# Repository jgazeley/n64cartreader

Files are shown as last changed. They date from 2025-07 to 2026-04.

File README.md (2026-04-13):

# N64 Pico Cart Reader V2

A simple, open-source N64 cartridge reader powered by a Raspberry Pi Pico. Plug it in via USB to dump ROMs and back up saves directly to your computer using a web browser or command line.

Device in Action

## Features

- **Full ROM dumping** for retail N64 cartridges (up to 32 MB)
- **Save read/write/restore** for all retail save types:
  - SRAM (e.g. 1080 Snowboarding, Ocarina of Time)
  - EEPROM 4K/16K (e.g. GoldenEye, Super Mario 64)
  - FlashRAM (e.g. Majora's Mask, Pokemon Stadium)
  *(For a full list of N64 games and their save types, see [Micro-64's Game Save List](http://micro-64.com/database/gamesave.shtml))*
- **Controller Pak (MPK)** export/import
- **GameShark** cartridge export/import/restore
- **Web Serial GUI** — runs in Chrome/Edge, no install required
- **Python CLI** for all other users
- **3.3V-native design** — no level shifting needed, lower BOM cost
- **Automatic cart identification** — detects game, ROM size, and save type from a built-in catalog

## Getting Started

See [docs/GETTING_STARTED.md](docs/GETTING_STARTED.md) for full setup instructions.

### Quick Start

1. Flash the `pico_headless_demo.uf2` firmware to your Pico (hold BOOTSEL while plugging in USB, then drag the file onto the drive).
2. Insert an N64 cartridge.
3. Open the [Web Serial UI](host-tools/web/index.html) in Chrome or Edge, or use a CLI:

**Windows (PowerShell):**
```powershell
./host-tools/powershell/N64CartReader.ps1 -Port COM5
```

**Windows/macOS/Linux (Python):**
```bash
# example for windows
python3 host-tools/python/pico_pak_n64_magic_cli.py --port /dev/ttyCOM5 n64-cart-id --rescan
# example for linux
python3 host-tools/python/pico_pak_n64_magic_cli.py --port /dev/ttyACM0 n64-cart-id --rescan
```

## Project Layout

```
firmware/
  rp2040/          C-based firmware for the Raspberry Pi Pico (timing-critical bus logic)
host-tools/
  powershell/      Native CLI for Windows (no setup needed); also supports macOS/Linux
  python/          Cross-platform CLI for validation, diagnostics, and batch scripts
  web/             Easiest, driverless browser-based interface using Web Serial
hardware/
  board/           V2 hardware project (KiCad PCB, schematics, and BOM)
enclosure/
  board/           3D-printable protective case (FreeCAD and STL files)
docs/              Technical guides, hardware documentation, and troubleshooting
LICENSES/          Third-party license texts for shared components
```

## Web Serial UI

The browser-based interface is the easiest way to use the reader. It works in Chrome and Edge via the Web Serial API. No drivers or software installation required.

Open `host-tools/web/index.html` directly in your browser, click Connect, and the UI will detect your cartridge and present options for ROM dumping, save export/import, and GameShark operations.

See [docs/WEB_SERIAL_UI.md](docs/WEB_SERIAL_UI.md) for details.

## Python CLI

The Python CLI provides full access to all device capabilities and is used for bench testing, validation, and scripted workflows.

```bash
cd host-tools/python

# Identify the cartridge
python3 pico_pak_n64_magic_cli.py --port /dev/ttyACM0 n64-cart-id --rescan

# Export a save
python3 pico_pak_n64_magic_cli.py --port /dev/ttyACM0 n64-export --out my_save.bin --sha256

# Import a save with verification
python3 pico_pak_n64_magic_cli.py --port /dev/ttyACM0 n64-import --in my_save.bin --verify

# Dump the full ROM
python3 pico_pak_n64_magic_cli.py --port /dev/ttyACM0 n64-rom-dump --out my_rom.z64

# Run the validation matrix
python3 n64_validation_matrix.py --port /dev/ttyACM0
```

## PowerShell CLI

A native alternative for Windows users (no installation required). Works with the built-in PowerShell 5.1 or PowerShell 7+ (`pwsh`) on any platform. See [Getting Started](docs/GETTING_STARTED.md) for Windows execution policy setup.

```powershell
# Interactive menu (use COMx on Windows, /dev/ttyACM0 on Linux)
./host-tools/powershell/N64CartReader.ps1 -Port COM5

# Export a save
./host-tools/powershell/Export-Save.ps1 -Port COM5 -Out my_save.bin

# Import a save with verification
./host-tools/powershell/Import-Save.ps1 -Port COM5 -In my_save.bin -Verify

# Dump the full ROM
./host-tools/powershell/Dump-Rom.ps1 -Port COM5 -Out my_rom.z64
```

## Building the Firmware

Requires the [Pico SDK](https://github.com/raspberrypi/pico-sdk) and CMake.

```bash
cd firmware/rp2040
export PICO_SDK_PATH=/path/to/pico-sdk
cmake -S . -B build
cmake --build build -j4 --target pico_headless_demo
```

Flash with picotool or drag `build/pico_headless_demo.uf2` onto the Pico in BOOTSEL mode.

## Hardware

The V2 board is a single PCB with an integrated N64 cartridge slot and Raspberry Pi Pico footprint. The design is in KiCad under `hardware/board/kicad/`.

Power is supplied through USB. The RP2040 runs at 3.3V, which matches N64 cartridge logic levels directly.

Pin mapping and board documentation are in [docs/HARDWARE.md](docs/HARDWARE.md).

## Troubleshooting

**Cartridge not detected or garbled header:**
Remove the cartridge, clean the edge connector contacts with isopropyl alcohol and a cotton swab, and reseat firmly.

**EEPROM save shows `type=none` after cart swap:**
Run `n64-cart-id --rescan` or retry 3-5 times. The Joybus bus needs a moment to settle after a physical swap.

**Controller probe returns `IO_ERR`:**
EEPROM cartridges and controllers share the same Joybus data line. Unplug one to test the other.

**Web Serial won't connect:**
Web Serial requires Chrome or Edge. Firefox and Safari are not supported. Make sure no other application (terminal, serial monitor) has the port open.

## V1 Legacy

The original N64 Cart Reader was built on an Arduino Mega 2560 with an SD card for storage and a serial terminal interface. That design is preserved in the `legacy/v1-arduino` branch.

See [docs/V1_LEGACY.md](docs/V1_LEGACY.md) for details on the original hardware.

## Acknowledgements

N64 Pico Cart Reader V2 was designed and implemented by Jayson Gazeley as an RP2040-based successor to the original Arduino N64 Cart Reader.

The project builds on prior open-source preservation work, especially:

- **[Sanni Cart Reader](https://github.com/sanni/cartreader)** (GPL-3.0) — foundational N64 cartridge interfacing logic
- **[drmdmp64_mass / DreamDumper64](https://github.com/nopjne/drmdmp64_mass)** by nopjne (BSD-2-Clause) — Joybus PIO and EEPROM reference implementation
- **skaman** — multi-console cart-reader modules
- **hkz & themanbehindthecurtain** — FlashRAM command documentation
- **Andrew Brown & Peter Den Hartog** — N64 controller protocol
- **libdragon** — N64 controller checksums

See [docs/CREDITS_AND_PRIOR_ART.md](docs/CREDITS_AND_PRIOR_ART.md) for full attribution and [docs/LICENSING.md](docs/LICENSING.md) for license details.

## References

- [Joybus Protocol](https://n64brew.dev/wiki/Joybus_Protocol)
- [N64 Hardware Architecture](https://www.copetti.org/writings/consoles/nintendo-64/)

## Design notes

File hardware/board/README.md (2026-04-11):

# N64 Pico Cart Reader V2 Hardware

This directory contains the custom KiCad PCB design files and fabrication outputs for the N64 Pico Cart Reader V2.

## Directory Structure

- **`docs/`**: Hardware documentation, including the current `PINMAP.md` that outlines the routing between the Raspberry Pi Pico and the N64 cartridge slot.
- **`kicad/`**: The complete, editable KiCad project (`.kicad_pro`, `.kicad_sch`, `.kicad_pcb`).
  - **`lib/`**: Custom project symbols and footprints (e.g., the N64 cartridge slot footprint).
- **`fabrication/`**: Board manufacturing outputs.
  - **`jlcpcb/`**: A known-good `.zip` file containing the Gerbers and drill files formatted and ready for upload to JLCPCB.
  - **`gerbers/`**: The individual, extracted Gerber and drill files.

## Hardware Quirk: EEPROM Latency
When testing the hardware, note that after a physical cartridge swap, the initial Joybus detection may return `type=none` for EEPROM saves. This is a known hardware limitation. It typically requires 3-5 retries or an explicit software rescan to allow the bus to settle.

## Licensing
The hardware design files (schematics, PCB layouts, custom footprints) are released under the [Creative Commons Attribution 4.0 International (CC BY 4.0)](https://creativecommons.org/licenses/by/4.0/) license. This license was chosen to maintain continuity with the hardware licensing of the original V1 Arduino-based project from which this work conceptually descends.

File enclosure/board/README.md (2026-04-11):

# N64 Pico Cart Reader V2 Enclosure

This directory contains the 3D printable enclosure files for the N64 Pico Cart Reader V2.

## Files

- **`freecad/`**: Original FreeCAD (`.FCStd`) source files. These are provided so you can remix, modify, or adjust the case design to fit your specific printing needs.
- **`stl/`**: Ready-to-print STL meshes. Import these directly into your slicer of choice (e.g., Cura, PrusaSlicer, OrcaSlicer) to generate the toolpaths for your 3D printer.

## Printing Recommendations

- **Material:** PLA, PETG, or ABS are all suitable.
- **Layer Height:** 0.2mm is recommended for a good balance of quality and print speed.
- **Infill:** 15-20% is typically sufficient for an enclosure.
- **Supports:** Check your slicer preview; some overhanging sections for the ports or mounting posts may require minimal supports depending on your printer's bridging capabilities.

## Licensing
The enclosure designs are provided under the [Creative Commons Attribution 4.0 International (CC BY 4.0)](https://creativecommons.org/licenses/by/4.0/) license.

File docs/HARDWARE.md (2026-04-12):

# Hardware Overview

## V2 Single-Board Reader (RP2040)

The V2 board is a single PCB integrating an N64 cartridge slot and a Raspberry Pi Pico (RP2040). It replaces the original Arduino Mega 2560 + shield design with a simpler, lower-cost solution.

### Design Highlights

- **3.3V-native:** The RP2040 and N64 cartridges both operate at 3.3V. No level shifters required.
- **No SD card:** All data transfer happens over USB. Saves and ROMs are streamed directly to the host.
- **Low BOM:** The minimum build requires the PCB, a Pico, the N64 cartridge slot connector, and passive components.
- **USB-powered:** No external power supply needed.

### Pin Mapping

The RP2040 GPIO assignments are defined in `firmware/rp2040/include/n64/pins.h`.

| Function | GPIO | N64 Slot Pin | Notes |
|---|---|---|---|
| AD0-AD15 | GPIO 0-15 | AD0-AD15 | 16-bit multiplexed address/data bus |
| SYSTEM_RESET | GPIO 16 | RESET | Active-high for bus reset |
| /WRITE | GPIO 17 | /WR | Active-low write strobe |
| /READ | GPIO 18 | /RD | Active-low read strobe |
| ALE_H | GPIO 19 | ALE_H | Address latch enable (high byte) |
| ALE_L | GPIO 20 | ALE_L | Address latch enable (low byte) |
| EEPROM DATA | GPIO 21 | EE_DAT | Shared Joybus data line for cartridge EEPROM/RTC and controller |
| EEPROM CLK | GPIO 22 | EE_CLK | Clock for cartridge EEPROM transfers |

### Power

- **VCC (3.3V):** Supplied from the Pico's onboard regulator or an external 3.3V LDO (e.g. AP2112K-3.3) fed from USB 5V.
- **GND:** Shared ground between Pico, PCB, and cartridge slot.

If using an external LDO, ensure solid solder joints on all pins — a high-resistance connection on the regulator can cause voltage sag under load, resulting in save write failures while reads appear normal.

### KiCad Source

The schematic and PCB layout are in `hardware/board/kicad/`. Custom footprints for the N64 cartridge slot, controller port, and Pico module are in the project-local library under `hardware/board/kicad/lib/`.

### Controller Port

The optional controller port shares the Joybus data line (GPIO 21) with EEPROM cartridges. When both are connected, bus contention will occur. Use one at a time.

## Legacy Hardware

The original V1 design used an Arduino Mega 2560 with a shield PCB, SD card, and level shifters. See [V1_LEGACY.md](V1_LEGACY.md) for details. V1 hardware files are preserved in the `legacy/v1-arduino` branch.

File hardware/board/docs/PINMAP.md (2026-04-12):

# N64 Pico-Pak: Connectivity Source of Truth

**Reference Code:** `/srv/agent_share/n64/n64-fw/include/n64/pins.h`

| Function | Pin (pins.h) | Target MCU (RP2040) | N64 Slot Pin | Notes |
| :--- | :--- | :--- | :--- | :--- |
| **ADBUS 0-15** | `GPIO0-15` | GPIO0 - GPIO15 | AD0 - AD15 | 16-bit Multiplexed Bus |
| **SYSTEM_RESET** | `GPIO16` | GPIO16 | RESET | Active-High for Bus |
| **WR_STROBE** | `GPIO17` | GPIO17 | /WRITE | Active-Low |
| **RD_STROBE** | `GPIO18` | GPIO18 | /READ | Active-Low |
| **ALE_H** | `GPIO19` | GPIO19 | ALE_H | Address Latch High |
| **ALE_L** | `GPIO20` | GPIO20 | ALE_L | Address Latch Low |
| **EEPROM DATA** | `GPIO21` | GPIO21 | EE_DAT | Shared Joybus data line for cartridge EEPROM/RTC and controller |
| **EEPROM CLK** | `GPIO22` | GPIO22 | EE_CLK | Clock for cartridge EEPROM transfers |

## Power Requirements
- **VCC:** +3.3V (RP2040 and N64 Logic)
- **VBUS:** +5V (Optional, for USB or specific N64 lines)
- **GND:** Shared Ground Plane

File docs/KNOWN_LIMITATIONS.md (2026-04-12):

# Known Limitations

While the N64 Pico Cart Reader V2 provides stable support for retail N64 cartridges, there are several known limitations and experimental features.

## Reproduction Cartridge Support
Reproduction cartridges vary widely in flash memory, CPLD/mapper logic, and save translation hardware. Retail N64 cartridges remain the primary stable release target.
- **ROM Dumping:** Some reproduction cartridges may require extra initialization and are not guaranteed to behave exactly like retail mask ROM boards.
- **Saves:** Reproduction cartridges that translate N64 Joybus save commands into non-retail save hardware may not be supported unless that board design has been explicitly validated.

## Hot-Swap Detection
Cartridges should be rescanned after insertion or swapping. If an EEPROM cartridge reports no save after a hot swap, reseat the cartridge and run rescan again before attempting save operations.

## Joybus Contention
Cartridge EEPROM and the optional controller port share the Joybus data line on this board.
- **Issue:** Probing an EEPROM cartridge and a controller simultaneously can produce `IO_ERR` or bitwise collisions.
- **Workaround:** Unplug the controller to test the cartridge save, or unplug the cartridge to test the controller.

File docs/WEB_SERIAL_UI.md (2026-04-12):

# Web Serial UI

The N64 Pico Cart Reader V2 includes a browser-based interface that communicates with the device over USB using the Web Serial API. No drivers or software installation required.

## Requirements

- **Browser:** Google Chrome or Microsoft Edge (desktop). Firefox and Safari do not support Web Serial.
- **Connection:** The Pico must be flashed with the headless firmware and connected via USB.
- **No other serial connections:** Close any terminal emulator or serial monitor that might have the port open.

## Opening the UI

Open `host-tools/web/index.html` directly in your browser. It runs entirely client-side — no server or internet connection needed.

## Connecting

1. Click **Connect**.
2. A browser dialog lists available serial ports. Select the Pico (usually the only CDC device listed).
3. The status indicator turns green and the firmware version is displayed.

## Loading the Cart Catalog

The UI can automatically identify cartridges using the bundled ROM catalog:

1. Open the Web UI; it loads the bundled catalog from `host-tools/web/n64_catalog.js`.
2. To override it later, drop the source catalog at `host-tools/n64.txt` onto the catalog drop zone.
3. Once loaded, the catalog persists for the session.

With the catalog loaded, rescanning a cartridge reports the game title, region, save type, and ROM size.

## GamePak Operations

After connecting and inserting a cartridge:

- **Rescan** — re-detects the cartridge and updates game info.
- **Export Save** — reads the cartridge save (SRAM, EEPROM, or FlashRAM) and downloads it as a binary file.
- **Import Save** — writes a save file back to the cartridge. Select a file from your computer when prompted.
- **Dump ROM** — reads the full ROM and downloads it as a `.z64` file.
- **ROM Header** — displays the first 64 bytes of the ROM header.

## GameShark Operations

With a GameShark Pro cartridge inserted:

- **GameShark Info** — reads the GameShark header and flash ID.
- **Export GameShark** — dumps the full GameShark flash contents.
- **Import GameShark** — writes a GameShark image back to the cartridge.

## Controller Operations

With an N64 controller plugged into the reader's controller port:

- **Controller Probe** — detects the controller and reports whether a Controller Pak (MPK) is present.
- **Export MPK** — reads the Controller Pak contents and downloads them.
- **Import MPK** — writes a Controller Pak image back.

Note: EEPROM cartridges and controllers share the same Joybus data line. Unplug one to use the other without bus contention.

## Troubleshooting

**"Web Serial API not available":**
You need Chrome or Edge. Other browsers do not support this API.

**Port not listed in the browser dialog:**
Make sure no other application has the serial port open. On Linux, you may need to add your user to the `dialout` group:
```bash
sudo usermod -aG dialout $USER
```
Log out and back in for the change to take effect.

**Connection drops during large transfers:**
Check your USB cable. Some cables are charge-only and do not support data. Try a different cable or a shorter one.

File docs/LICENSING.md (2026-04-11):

# Licensing

The N64 Pico Cart Reader V2 project encompasses several different domains, each with its own licensing terms to respect prior art and open-source boundaries.

## Firmware and Software
The firmware and host software components are open source and subject to the following licenses:

- **GPL-3.0:** Portions of the firmware and software derived from the [Sanni Cart Reader / Open Source Cartridge Reader](https://github.com/sanni/cartreader) project are licensed under the GNU General Public License v3.0. See `LICENSES/GPL-3.0.txt`.
- **BSD-2-Clause:** The Joybus PIO and EEPROM implementation derived in part from [drmdmp64_mass by nopjne](https://github.com/nopjne/drmdmp64_mass) are covered by the BSD-2-Clause license. See `LICENSES/BSD-2-Clause.txt`.

Where applicable, source files contain specific attribution headers indicating their origin and licensing:

**For files derived from Sanni:**
```c
/*
 * Derived from the Open Source Cartridge Reader / sanni Cart Reader project.
 * Original project: https://github.com/sanni/cartreader
 * Original license: GPL-3.0
 *
 * Modified by Jayson Gazeley for N64 Pico Cart Reader V2.
 */
```

**For files derived from or based on drmdmp64_mass:**
```c
/*
 * Joybus/EEPROM PIO implementation derived in part from:
 *   drmdmp64_mass by nopjne
 *   https://github.com/nopjne/drmdmp64_mass
 *
 * Original source files identify core code as BSD-2-Clause.
 * Modified by Jayson Gazeley for N64 Pico Cart Reader V2.
 */
```

## Hardware and Enclosure
Hardware design files (KiCad schematics, PCB layouts, Gerber files) and mechanical enclosure models (FreeCAD, STL files) are licensed separately from the firmware and software. Check the specific `hardware/` and `enclosure/` directories for their respective licensing terms (e.g., CERN-OHL or Creative Commons).

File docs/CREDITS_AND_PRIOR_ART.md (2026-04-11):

# Credits and Prior Art

N64 Pico Cart Reader V2 was designed and implemented by Jayson Gazeley as an RP2040-based successor to the original Arduino N64 Cart Reader.

The project builds on prior open-source preservation work, and we extend our deep gratitude to the following projects and their authors:

## Sanni Cart Reader / Open Source Cartridge Reader
- **Project:** [https://github.com/sanni/cartreader](https://github.com/sanni/cartreader)
- **License:** GPL-3.0
- **Contribution:** The original foundational logic for N64 cartridge interfacing, save type identification, and overall architecture that inspired this V2 RP2040 port. Portions of the firmware and software in this project are derived from the Sanni Cart Reader.

## drmdmp64_mass / DreamDumper64
- **Author:** nopjne
- **Project:** [https://github.com/nopjne/drmdmp64_mass](https://github.com/nopjne/drmdmp64_mass)
- **License:** BSD-2-Clause
- **Contribution:** Crucial reference and derived implementations for the Joybus PIO, EEPROM handling, and baseline RP2040 N64 cartridge interface logic.

Thank you to the broader N64 preservation and homebrew community for documenting the hardware quirks that made this project possible.

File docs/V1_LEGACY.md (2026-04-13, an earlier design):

# V1 Legacy: Arduino N64 Cart Reader

The original N64 Cart Reader (V1) was built on an Arduino Mega 2560 with an SD card for local storage and a serial terminal for control.

## V1 Hardware

- **MCU:** ATmega2560 (Arduino Mega 2560 or Mega 2560 Pro)
- **Storage:** SD card slot for saving ROMs and save files
- **Interface:** USB serial terminal (PuTTY, screen, or similar)
- **Logic levels:** 5V MCU with 3.3V level shifting to the N64 cartridge bus
- **Additional features:** RTC module, status LED, buzzer

The V1 board was a shield that plugged onto the Arduino Mega. It required desoldering the Arduino's pin headers for a flush fit — a significant barrier for less experienced builders.

## V1 Software

The V1 firmware was derived from the [Sanni Cart Reader](https://github.com/sanni/cartreader) project and ran as an interactive serial menu. Users navigated a text-based menu over a terminal emulator to:

- Read ROM data to SD card
- Read/write save data (SRAM, EEPROM, FlashRAM)
- Test controller and Controller Pak

Host-side operation required a serial terminal application:
- **Windows:** PuTTY
- **macOS/Linux:** `screen /dev/ttyXXXX 9600`
- **Android:** Serial USB Terminal app with USB-OTG adapter

## Why V2

V2 replaced the ATmega2560 with an RP2040 (Raspberry Pi Pico) to address V1's limitations:

| | V1 (ATmega2560) | V2 (RP2040) |
|---|---|---|
| Logic level | 5V (needs level shifting) | 3.3V native |
| Storage | SD card on the device | USB streaming to host |
| Interface | Serial terminal menu | Web Serial GUI + Python/PowerShell CLI |
| Speed | ~100 KB/s ROM dump | ~1 MB/s ROM dump |
| BOM cost | Higher (Mega + shield + SD + RTC + level shifters) | Lower (Pico + PCB + passives) |
| Build difficulty | Header desoldering required | Standard through-hole/SMD soldering |

## Where to Find V1 Code

- The V1 branch history is preserved at `legacy/v1-arduino`.
- The upstream Sanni Cart Reader project is at [github.com/sanni/cartreader](https://github.com/sanni/cartreader).

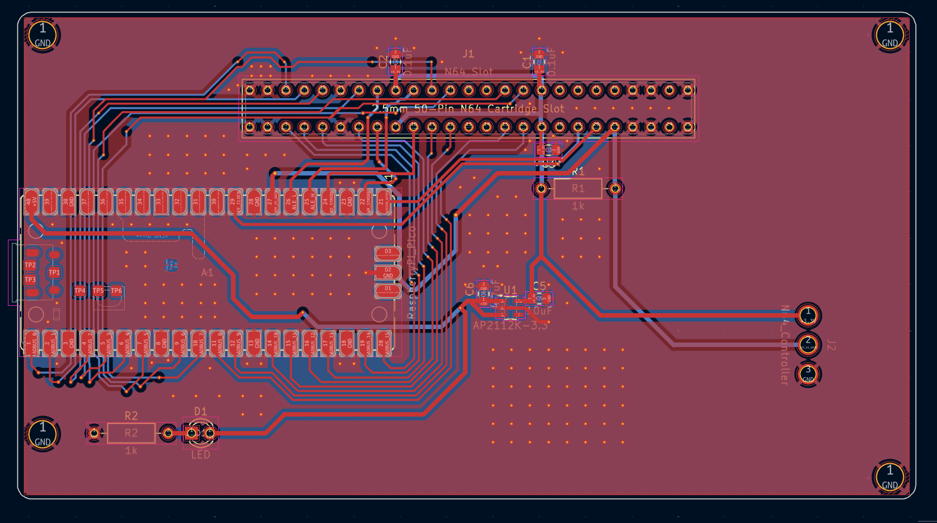
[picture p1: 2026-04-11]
hardware/board/kicad/board.png

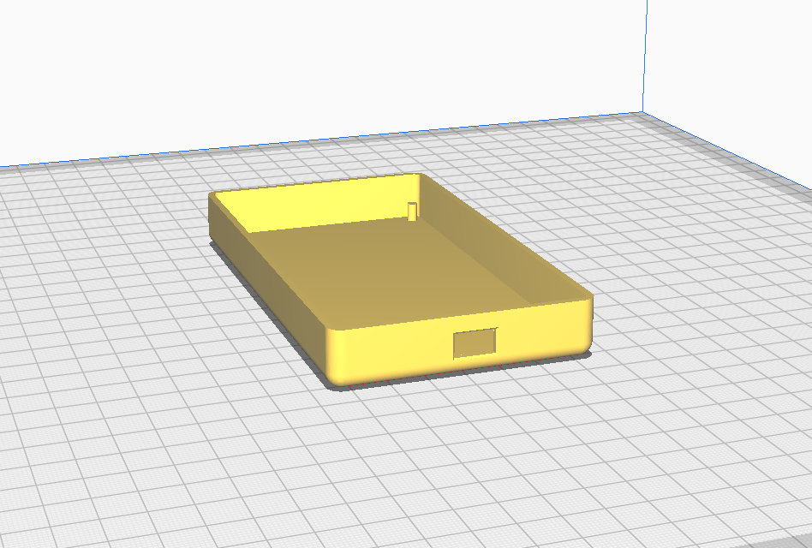
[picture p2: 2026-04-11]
enclosure/board/case_bottom.png

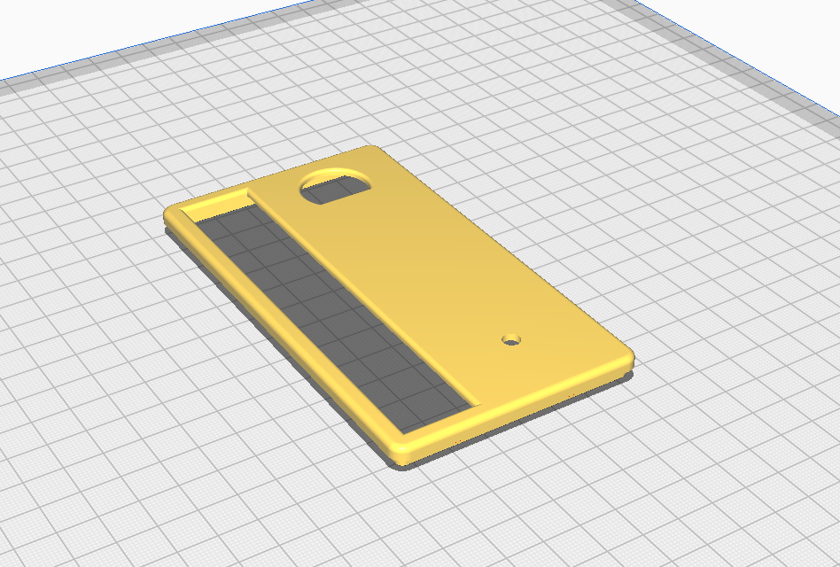
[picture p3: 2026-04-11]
enclosure/board/case_top.png

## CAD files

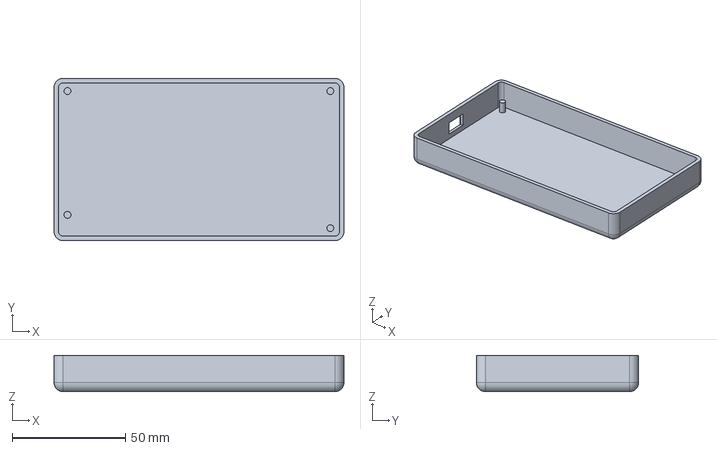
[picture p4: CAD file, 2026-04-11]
enclosure/board/freecad/n64_board-bottom.FCStd
128.0 x 71.6 x 16.0 mm

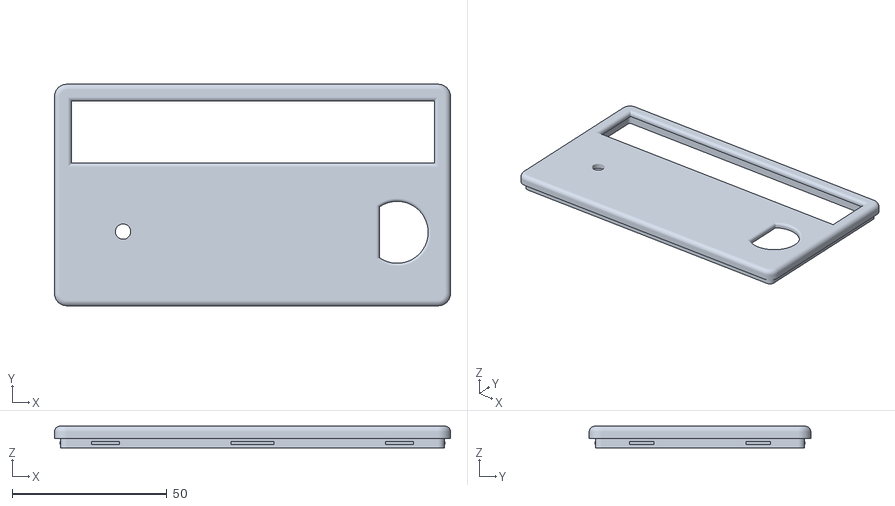
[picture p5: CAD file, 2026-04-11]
enclosure/board/stl/n64_board-top.stl
128.0 x 71.6 x 7.00

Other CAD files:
enclosure/board/stl/n64_board-bottom.stl

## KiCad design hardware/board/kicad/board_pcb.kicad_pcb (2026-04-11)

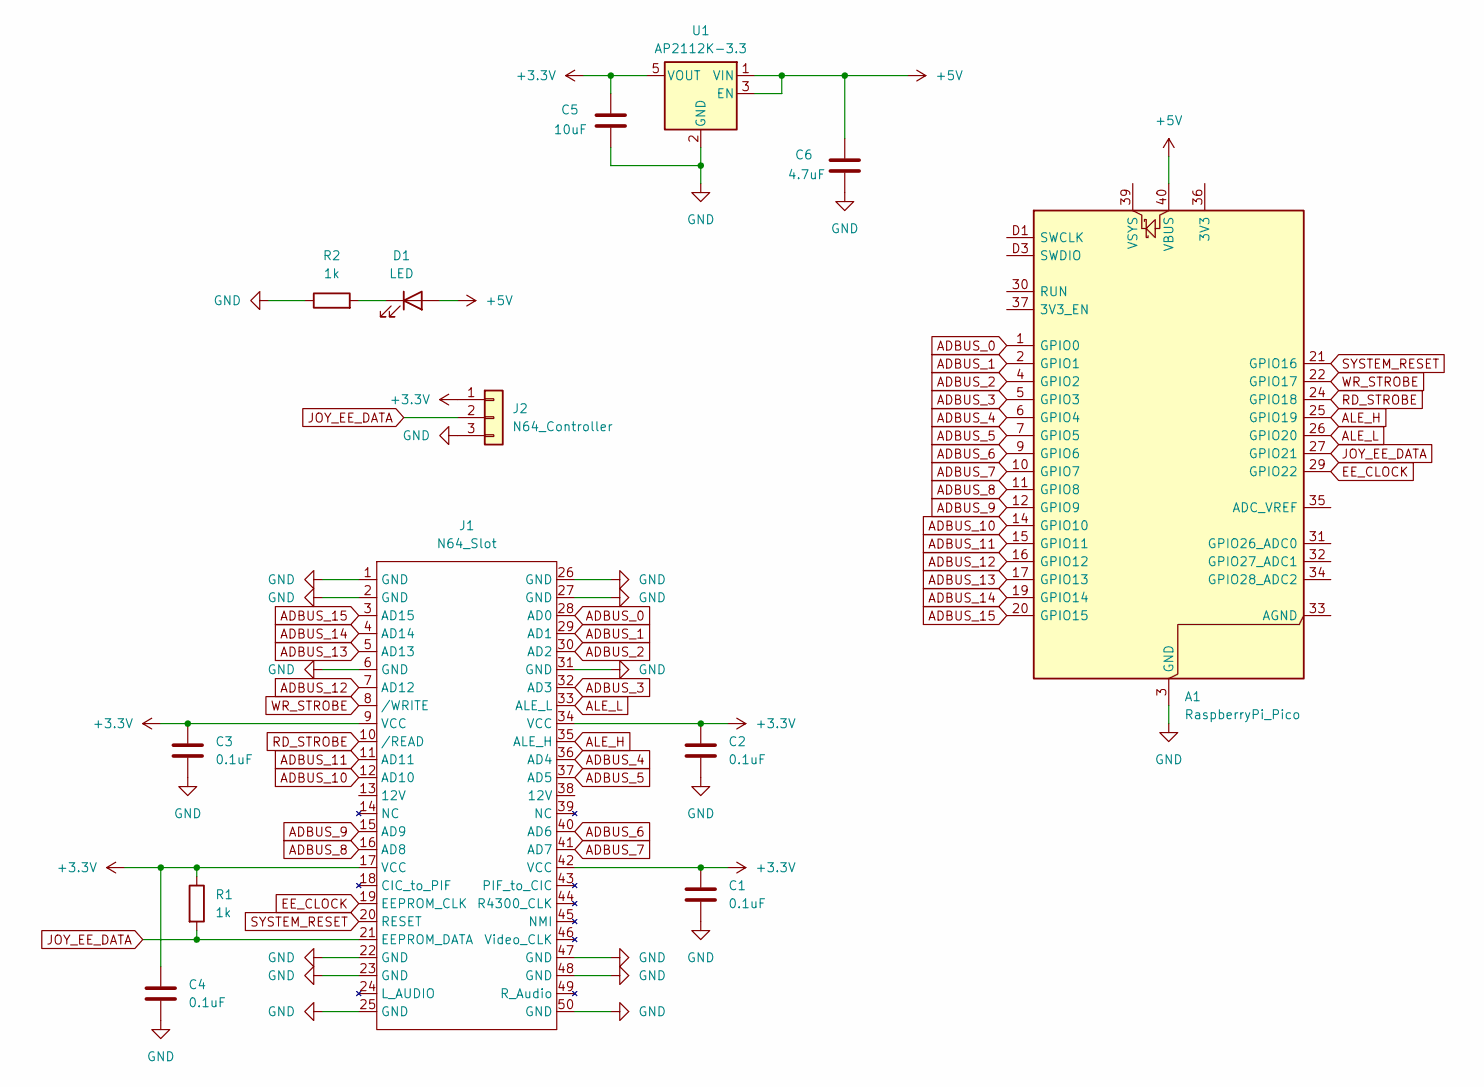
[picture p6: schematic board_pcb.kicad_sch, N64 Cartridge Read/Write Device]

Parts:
A1: RaspberryPi_Pico; RaspberryPi_Pico_SMD
C1, C2, C3, C4: 0.1uF; C_0805_2012Metric_Pad1.18x1.45mm_HandSolder
C5: 10uF; C_0805_2012Metric_Pad1.18x1.45mm_HandSolder
C6: 4.7uF; C_0805_2012Metric_Pad1.18x1.45mm_HandSolder
D1: LED; LED_D3.0mm
J1: N64_Slot
J2: N64_Controller; Controller_Port_3Pin
R1, R2: 1k; R_Axial_DIN0207_L6.3mm_D2.5mm_P10.16mm_Horizontal
U1: AP2112K-3.3; SOT-23-5

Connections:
+3.3V: C1.1, C2.1, C3.1, C4.1, C5.1, J1.9 (VCC), J1.17 (VCC), J1.34 (VCC), J1.42 (VCC), J2.1, R1.1, U1.5 (VOUT)
+5V: A1.40 (VBUS), C6.1, D1.2 (A), U1.1 (VIN), U1.3 (EN)
ADBUS_0: A1.1 (GPIO0), J1.28 (AD0)
ADBUS_1: A1.2 (GPIO1), J1.29 (AD1)
ADBUS_2: A1.4 (GPIO2), J1.30 (AD2)
ADBUS_3: A1.5 (GPIO3), J1.32 (AD3)
ADBUS_4: A1.6 (GPIO4), J1.36 (AD4)
ADBUS_5: A1.7 (GPIO5), J1.37 (AD5)
ADBUS_6: A1.9 (GPIO6), J1.40 (AD6)
ADBUS_7: A1.10 (GPIO7), J1.41 (AD7)
ADBUS_8: A1.11 (GPIO8), J1.16 (AD8)
ADBUS_9: A1.12 (GPIO9), J1.15 (AD9)
ADBUS_10: A1.14 (GPIO10), J1.12 (AD10)
ADBUS_11: A1.15 (GPIO11), J1.11 (AD11)
ADBUS_12: A1.16 (GPIO12), J1.7 (AD12)
ADBUS_13: A1.17 (GPIO13), J1.5 (AD13)
ADBUS_14: A1.19 (GPIO14), J1.4 (AD14)
ADBUS_15: A1.20 (GPIO15), J1.3 (AD15)
ALE_H: A1.25 (GPIO19), J1.35 (ALE_H)
ALE_L: A1.26 (GPIO20), J1.33 (ALE_L)
EE_CLOCK: A1.29 (GPIO22), J1.19 (EEPROM_CLK)
GND: A1.3 (GND), A1.8 (GND), A1.13 (GND), A1.18 (GND), A1.23 (GND), A1.28 (GND), A1.38 (GND), A1.D2 (GND), C1.2, C2.2, C3.2, C4.2, C5.2, C6.2, J1.1 (GND), J1.2 (GND), J1.6 (GND), J1.22 (GND), J1.23 (GND), J1.25 (GND), J1.26 (GND), J1.27 (GND), J1.31 (GND), J1.47 (GND), J1.48 (GND), J1.50 (GND), J2.3, R2.1, U1.2 (GND)
JOY_EE_DATA: A1.27 (GPIO21), J1.21 (EEPROM_DATA), J2.2, R1.2
unnamed: D1.1 (K), R2.2
RD_STROBE: A1.24 (GPIO18), J1.10 (/READ)
SYSTEM_RESET: A1.21 (GPIO16), J1.20 (RESET)
WR_STROBE: A1.22 (GPIO17), J1.8 (/WRITE)

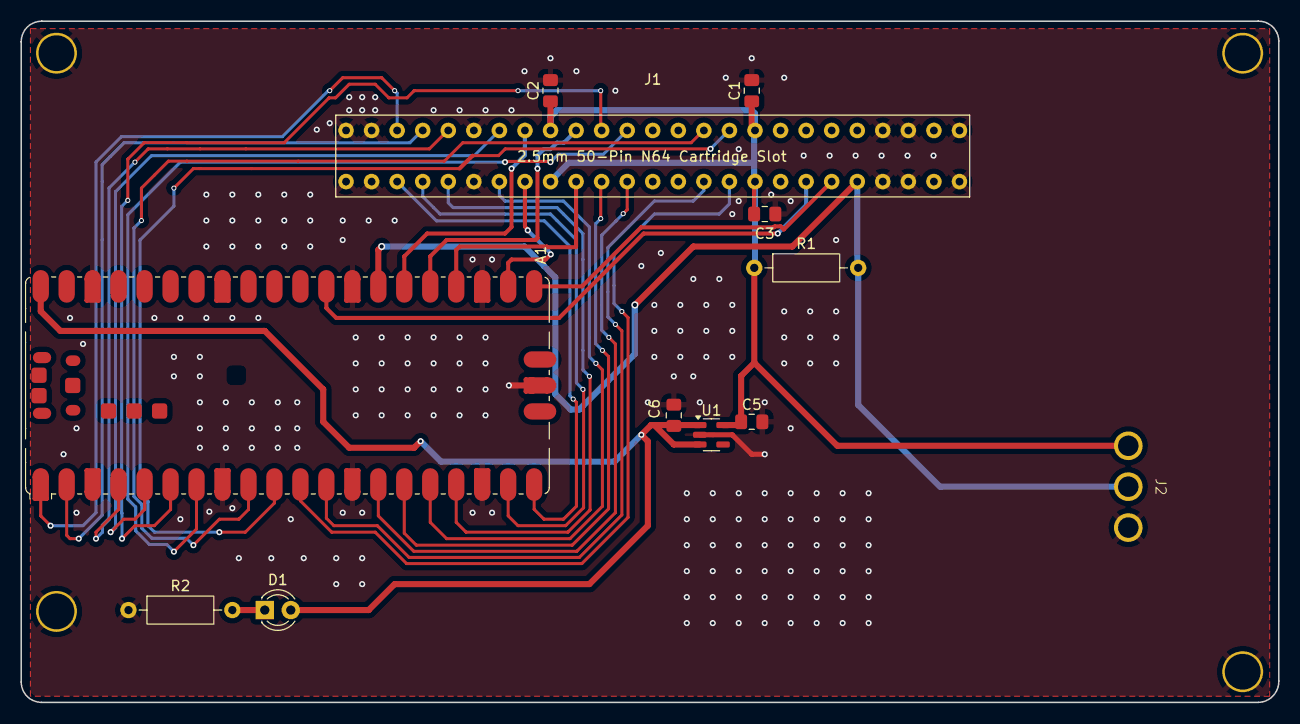
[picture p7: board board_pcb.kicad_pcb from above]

Board: 2 copper layers, 123.0 x 66.6 mm, 12 parts (0 on the bottom side), 27 nets.

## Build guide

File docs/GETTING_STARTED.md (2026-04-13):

# Getting Started

## What You Need

- **N64 Pico Cart Reader V2 board** (assembled, with Raspberry Pi Pico soldered)
- **USB cable** (Micro-USB for Pico, or USB-C if using a Pico variant with USB-C)
- **A host computer** (Windows, macOS, or Linux) or Android device with USB-OTG
- **One or more retail N64 cartridges**

Optional:
- **N64 Controller** with Controller Pak (for MPK backup/restore)
- **GameShark Pro** cartridge (for GameShark backup/restore)

## Step 1: Flash the Firmware

If your Pico is not already flashed with the V2 firmware:

1. Hold the **BOOTSEL** button on the Pico while plugging in the USB cable.
2. The Pico appears as a USB mass storage drive.
3. Drag `pico_headless_demo.uf2` onto the drive. The Pico reboots automatically.

To build the firmware from source, see the [Building the Firmware](#building-the-firmware) section below.

After flashing, the Pico enumerates as a USB CDC serial device:
- **Linux:** `/dev/ttyACM0` (or similar)
- **macOS:** `/dev/tty.usbmodemXXXX`
- **Windows:** `COMx` (visible in Device Manager under Ports)

## Step 2: Insert a Cartridge

Push the N64 cartridge firmly into the slot until it seats. A loose connection is the most common cause of read errors.

If the cartridge contacts are dirty, clean them with isopropyl alcohol and a cotton swab before inserting.

## Step 3: Connect and Use

### Option A: Web Serial UI (recommended for most users)

1. Open `host-tools/web/index.html` in **Chrome** or **Edge**.
2. Click **Connect** and select the Pico's serial port.
3. The UI detects the cartridge and shows game info, save type, and available operations.

No software installation required. Works on any OS with a supported browser. The Web UI includes a bundled cartridge catalog for automatic identification; if you ever need to override it, drag `host-tools/n64.txt` onto the catalog drop zone.

### Option B: Python CLI (recommended for users without a Chromium-based browser)

Requires Python 3.10+ and pyserial. If on Windows, install Python from python.org and check "Add python.exe to PATH" during setup. Install dependencies with:

**macOS/Linux:**
```bash
python3 -m pip install -r host-tools/python/requirements.txt
```

**Windows:**
```powershell
python -m pip install -r host-tools\python\requirements.txt
# Or if that fails:
py -m pip install -r host-tools\python\requirements.txt
```

The Python CLI auto-detects the Pico when exactly one Pico serial device is connected. If multiple Pico devices are connected, or if auto-detect fails, specify the port manually with `--port`.

On Windows, open **Device Manager -> Ports (COM & LPT)** and look for the Pico/USB serial port, then use that COM name, for example `--port COM5`. In the interactive CLI, choose **U -> P** to list detected ports and set the port without restarting the program.

The examples below use `python3`; on Windows, use `python` or `py` instead if that is how Python is installed on your system.

```bash
cd host-tools/python

# Check firmware version (auto-detects if exactly one Pico is connected)
python3 pico_pak_n64_magic_cli.py fw-version

# Check firmware version with an explicit port, if needed
python3 pico_pak_n64_magic_cli.py --port <PORT> fw-version

# Identify the cartridge
python3 pico_pak_n64_magic_cli.py --port <PORT> n64-cart-id --rescan

# Export save data
python3 pico_pak_n64_magic_cli.py --port <PORT> n64-export --out save.bin --sha256

# Import save data with verification
python3 pico_pak_n64_magic_cli.py --port <PORT> n64-import --in save.bin --verify

# Dump the full ROM
python3 pico_pak_n64_magic_cli.py --port <PORT> n64-rom-dump --out game.z64
```

### Option C: PowerShell CLI (native alternative for Windows)

The PowerShell scripts have zero external dependencies -- no pip, no packages, just PowerShell and a USB cable. This makes them a great option on Windows where PowerShell is already installed.

**Windows (PowerShell 5.1 is built in):**

You may need to allow script execution the first time. Open PowerShell and run:
```powershell
Set-ExecutionPolicy -Scope CurrentUser -ExecutionPolicy RemoteSigned
```
You only need to do this once. Then run scripts directly:
```powershell
# Interactive menu (use COMx on Windows)
.\host-tools\powershell\N64CartReader.ps1 -Port COM5

# Or run individual operations:

# Export save data
.\host-tools\powershell\Export-Save.ps1 -Port COM5 -Out save.bin

# Import save data with verification
.\host-tools\powershell\Import-Save.ps1 -Port COM5 -In save.bin -Verify

# Dump the full ROM
.\host-tools\powershell\Dump-Rom.ps1 -Port COM5 -Out game.z64
```

**macOS/Linux (requires PowerShell 7+):**

Install PowerShell 7 from https://github.com/PowerShell/PowerShell#get-powershell, then use `pwsh`:
```bash
# Interactive menu (use /dev/tty... on Linux/macOS)
pwsh host-tools/powershell/N64CartReader.ps1 -Port /dev/ttyACM0

# Export save data
pwsh host-tools/powershell/Export-Save.ps1 -Port /dev/ttyACM0 -Out save.bin

# Import save data with verification
pwsh host-tools/powershell/Import-Save.ps1 -Port /dev/ttyACM0 -In save.bin -Verify

# Dump the full ROM
pwsh host-tools/powershell/Dump-Rom.ps1 -Port /dev/ttyACM0 -Out game.z64
```

All scripts accept `-SaveType` to override auto-detection (e.g. `-SaveType sram`, `flashram`, `eeprom4k`, `eeprom16k`).

## Building the Firmware

Requires the [Raspberry Pi Pico SDK](https://github.com/raspberrypi/pico-sdk) and CMake.

```bash
cd firmware/rp2040
export PICO_SDK_PATH=/path/to/pico-sdk
cmake -S . -B build
cmake --build build -j4 --target pico_headless_demo
```

The output is `build/pico_headless_demo.uf2`. Flash it by dragging onto the Pico in BOOTSEL mode, or with picotool:

```bash
picotool load -f build/pico_headless_demo.uf2 -x
```

## Updating Firmware

To update an already-flashed Pico without pressing BOOTSEL:

```bash
picotool load -f build/pico_headless_demo.uf2 -x
```

picotool will automatically reboot the Pico into BOOTSEL mode, flash, and restart.

## Identifying Your Hardware

For one reader, the Web UI port picker or Python CLI auto-detect is usually enough. If multiple Pico readers are connected, identify the right one by unplugging the other readers temporarily, or use the operating system's port list:

- **Windows:** Open **Device Manager -> Ports (COM & LPT)** and look for the Pico/USB serial device, such as `COM5`.
- **macOS:** Check **System Information -> USB**, or list serial devices with `ls /dev/tty.usbmodem*`.
- **Linux:** List serial devices with `ls /dev/ttyACM*`; for stable names that include the USB serial number, use `ls -l /dev/serial/by-id/`.

In the Python interactive CLI, choose **U -> P** to list detected ports and set the active port without restarting.

## Next Steps

- [Web Serial UI guide](WEB_SERIAL_UI.md)
- [Hardware overview and pin map](HARDWARE.md)
- [Manufacturing test procedure](MANUFACTURING_TEST.md)
- [Known limitations](KNOWN_LIMITATIONS.md)

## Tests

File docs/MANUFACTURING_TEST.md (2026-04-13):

# Manufacturing Test Procedure

This procedure outlines the steps to verify a newly assembled N64 Pico Cart Reader V2 unit.

## Prerequisites
- A freshly soldered V2 board with a Raspberry Pi Pico installed.
- USB data cable compatible with the Pico installed on the board (typically Micro-USB for a standard Raspberry Pi Pico).
- Host computer with the V2 Python CLI tools installed.
- A known-good retail N64 cartridge (preferably one with SRAM, e.g., *1080 Snowboarding* or *Ocarina of Time*).
- An N64 Controller with a known-good Controller Pak (MPK).

## Step 1: Initial Firmware Flash
1. Hold the `BOOTSEL` button on the Pico while plugging in the USB cable to enter mass storage mode.
2. Flash the latest stable `pico_headless_demo.uf2` firmware.
3. Verify the device reboots and enumerates as a USB CDC serial device.

Typical serial port names:
- **Windows:** `COM5`
- **macOS:** `/dev/tty.usbmodemXXXX`
- **Linux:** `/dev/ttyACM0`

Run the commands below from the repository root. Replace `<PORT>` with the detected port. On Windows, use `python` or `py` instead of `python3` if needed.

## Step 2: Identification & Basic IO
1. Insert the known-good retail N64 cartridge.
2. Run the cart ID rescan:
   ```bash
   python3 host-tools/python/pico_pak_n64_magic_cli.py --port <PORT> n64-cart-id --rescan
   ```
3. **Pass Criteria:** The tool must successfully identify the cartridge header and report the correct ROM size and save type without I/O errors.

## Step 3: Save Media Test
1. Export the existing save:
   ```bash
   python3 host-tools/python/pico_pak_n64_magic_cli.py --port <PORT> n64-export --out mfg_test_save.bin
   # Or using PowerShell:
   # pwsh host-tools/powershell/Export-Save.ps1 -Port <PORT> -Out mfg_test_save.bin -Rescan
   ```
2. Verify the export completes successfully.
3. If a golden reference is available, run `host-tools/python/n64_cart_verify.py` for a write/readback verification cycle. Do not write test data to a customer or collector cartridge unless the original save has been backed up.

## Step 4: Controller Port Test
1. Remove the cartridge to avoid Joybus contention (if testing with an EEPROM cart).
2. Plug in the N64 Controller with the MPK.
3. Run the controller probe:
   ```bash
   python3 host-tools/python/pico_pak_n64_magic_cli.py --port <PORT> n64-controller-probe
   ```
4. **Pass Criteria:** The controller must be detected and report the presence of the memory pak.

## Step 5: Web Serial UI Check (Optional)
1. Open the Web Serial UI in a compatible browser.
2. Connect to the Pico.
3. Verify that the UI correctly populates the cartridge information.

If all steps pass, the hardware assembly is validated for core I/O functionality.

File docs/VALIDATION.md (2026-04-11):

# Validation

The N64 Pico Cart Reader V2 firmware undergoes rigorous bench testing against known-good "golden" references to ensure data integrity for ROM dumping and save management.

## Validation Matrix
The current stable V2 firmware has been hardware-tested against the following matrix, successfully passing round-trip export/import/restore checks and regression tests:

- **1080 Snowboarding:** SRAM read/write/restore and full ROM dump.
- **GoldenEye 007:** EEPROM (4K) read/write/restore using `.eeprom` and `.ebay` references.
- **The Legend of Zelda: Ocarina of Time:** SRAM read/write/restore.
- **The Legend of Zelda: Majora's Mask:** FlashRAM read/write/restore.
- **Controller Pak / MPK:** Repeated export verified against a golden reference.
- **GameShark:** Export/import/restore verified against known stable images.
- **Regression Check:** FlashRAM-to-SRAM swap regression. The old corruption path does not reproduce after firmware fixes.

## Methodology
Validation is performed using the provided Python CLI tools (e.g., `tools/n64_validation_matrix.py` and `tools/n64_cart_verify.py`).
- Saves are exported and their SHA256 hashes are strictly compared against canonical golden references.
- Destructive tests (writes) are followed by readback verification and a final export hash match to guarantee stability.

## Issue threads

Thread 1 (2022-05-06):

Controller slot: transfer pak

Nes-player4Life, 2022-05-06:
Is there anyway to customize this so Gameboy carts can be read through the n64 controller? From what I see this looks like a powerful device.

Will be interested is watching it develop.

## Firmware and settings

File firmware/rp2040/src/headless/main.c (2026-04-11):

#include "pico/stdlib.h"
#include "utils/transport.h"
#include "headless/protocol.h"

int main(void) {
    // Keep USB CDC stack alive, but do not run CLI/menu/parser.
    stdio_init_all();
    transport_init();
    headless_protocol_init();

    while (true) {
        headless_protocol_poll();
        sleep_ms(1);
    }
}

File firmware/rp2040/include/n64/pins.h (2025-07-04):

/**
 * @file pins.h
 * @brief Hardware pin definitions for the N64 interface.
 *
 * This file centralizes all GPIO pin assignments for the project.
 * If you change the physical wiring, this is the only file you
 * should need to edit.
 */
#ifndef N64_PINS_H
#define N64_PINS_H

// --- Main N64 AD-Bus Data Pins (GPIO0 - GPIO15) ---
#define N64_ADBUS_PIN_START     0   // The first GPIO pin of the 16-bit bus
#define N64_ADBUS_PIN_COUNT     16
#define N64_ADBUS_GPIO_MASK     (((1u << N64_ADBUS_PIN_COUNT) - 1) << N64_ADBUS_PIN_START)

// --- Main N64 AD-Bus Control Pins ---
#define N64_SYSTEM_RESET_PIN    16  // Active-high reset for the N64 bus
#define N64_ADBUS_WR_PIN        17  // Write strobe (active-low)
#define N64_ADBUS_RD_PIN        18  // Read strobe (active-low)
#define N64_ADBUS_ALE_H_PIN     19  // Address latch enable high
#define N64_ADBUS_ALE_L_PIN     20  // Address latch enable low

// --- Peripheral Bus Pins ---
#define N64_JOYBUS_DATA_PIN		21  // Data line for controllers (JoyBus)
#define N64_EEPROM_DATA_PIN     21  // Data line for cartridge EEPROM (can be shared)
#define N64_EEPROM_CLOCK_PIN    22  // Clock line for cartridge EEPROM

#endif // N64_PINS_H

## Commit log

2025-06-19 Refactor project structure
    [adapter.kicad_pcb, board_pcb.kicad_pcb, n64_board-bottom.stl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]
2025-06-26 feat: Completely reimplemented RP2040 firmware for N64 Cart Reader.
    This commit replaces the previous RP2040 firmware with a ground-up
    reimplementation, focusing on modularity and testability.
    **Key Changes/Features:**
    - New architecture for [mention high-level architectural changes, e.g., improved state machine, clearer module separation].
    - Integration of core modules like [list examples: e.g., redesigned ADbus, streamlined Joybus PIO].
    - Framework for future expansion with [e.g., dedicated device handlers, flexible CLI commands].
    - Successful low-level communication tests confirm basic functionality.
    **Current Status:**
    - Foundations are stable and tested.
    - Specific N64 Cart Reader fea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
    [adbus.c]
2025-07-04 MSC working, TODO: Fix flash writes; corrupt from 0x4005 to 0x407F
    [adbus.c, joybus.c]
2025-07-07 TODO: Fix flash writes; from 0x4000 to EOF
    [adbus.c, main.c]
2026-03-03 Snapshot of firmware after migration from Windows to Debian, presumed working but about to replace with newer working version. (pico-pak)
    [adapter.kicad_pcb, board_pcb.kicad_pcb, shield.kicad_pcb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]
2026-04-11 V2 launch: integrated repo with docs, cleanup, and validation
    - Firmware: RP2040 headless firmware with GameShark and utils support
    - Host tools: Python CLI, validation matrix, Web Serial UI
    - Hardware: V2 KiCad project with gerbers, fabrication outputs, custom footprint library
    - Enclosure: FreeCAD source and STL for V2 board case
    - Docs: README, GETTING_STARTED, HARDWARE, WEB_SERIAL_UI, V1_LEGACY,
    CREDITS_AND_PRIOR_ART, KNOWN_LIMITATIONS, LICENSING, VALIDATION,
    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
    [adapter.kicad_pcb, board_pcb.kicad_pcb, board_pcb.kicad_sch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]
2026-04-11 Fix host CLI build tag
    [integrity.py, ui.py]
2026-04-12 Clarify Joybus data pin naming
2026-04-13 Add PowerShell host tool and bump ROM export chunk size
    PowerShell CLI for N64 cart operations (dump ROM, export/import saves)
    with zero external dependencies — works with built-in PowerShell 5.1 on
    Windows or PowerShell 7+ on any platform. Tested on Linux against
    FlashRAM, SRAM, and EEPROM carts with byte-identical results to the
    Python CLI.
    Also increases ROM export chunk from 512 to 2048 bytes for faster dumps,
    and moves Python prerequisites into the correct doc section.
2026-04-13 Fix PowerShell scripts for Windows PowerShell 5.1 compatibility
    - Transport.ps1: Extract C# helper into $typeDef variable, try .NET
    Core assemblies first then fall back to bare Add-Type for .NET
    Framework. Redirect stderr (2>$null) so failed compilation attempts
    don't spew red error text to the user.
    - N64CartReader.ps1: Use labeled loop (:menuLoop) so "Q" actually
    exits the while loop instead of just the switch. Handle null input
    from Ctrl+D/EOF gracefully.
2026-04-13 Refine project layout and PowerShell descriptions for clarity
2026-04-13 Refine documentation hierarchy: Web UI as easiest, PowerShell as native Windows CLI
